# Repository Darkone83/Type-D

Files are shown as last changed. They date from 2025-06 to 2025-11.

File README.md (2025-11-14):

# Type D: Original Xbox TFT Display Project

<div align=center>
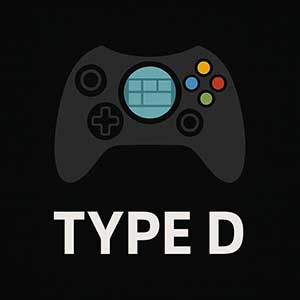
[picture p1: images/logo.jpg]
  

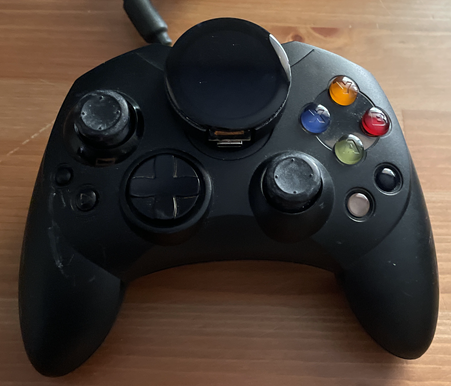
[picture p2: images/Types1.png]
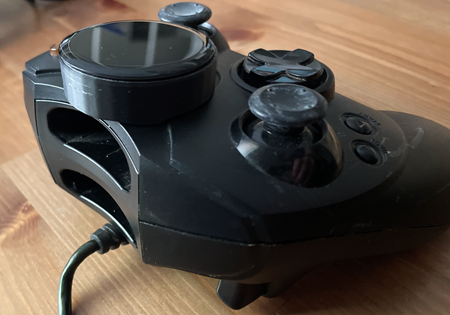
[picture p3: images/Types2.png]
  

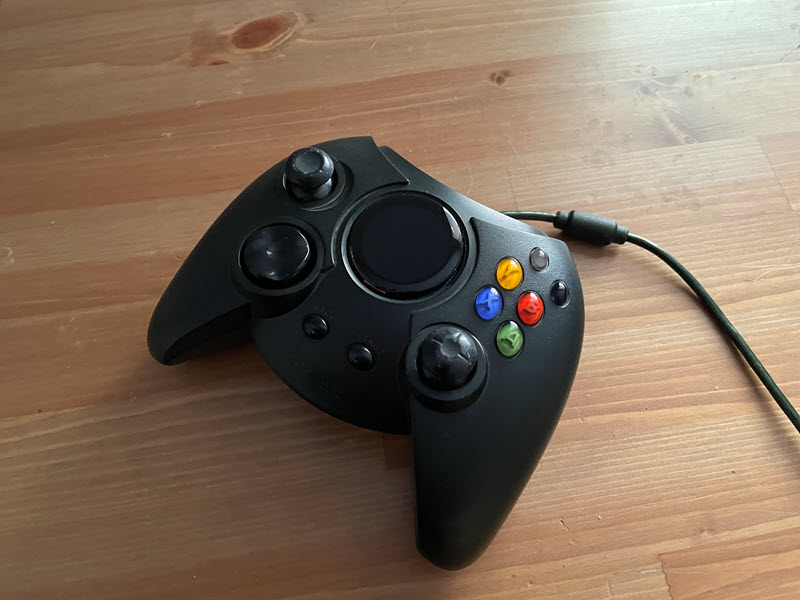
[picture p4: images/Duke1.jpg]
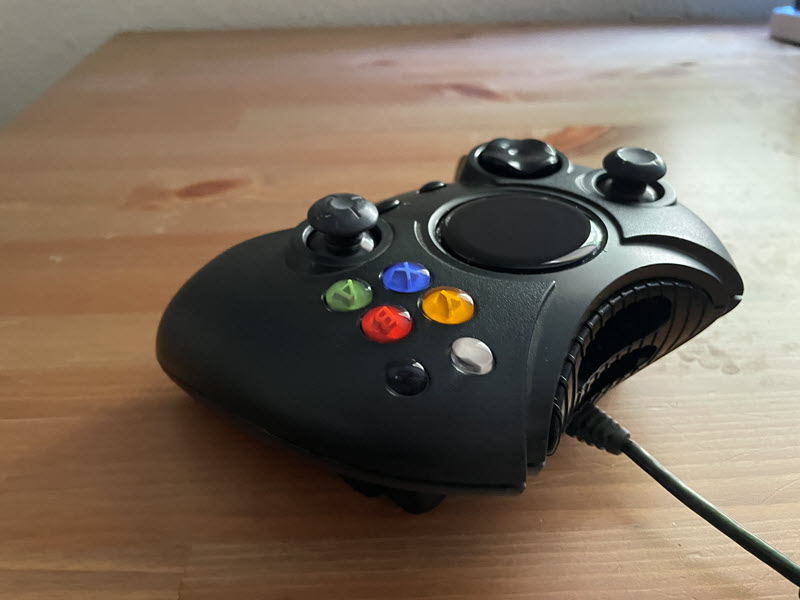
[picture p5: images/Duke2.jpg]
    
</div>



**Type D** is a two-part open-source system for the original Xbox, bringing a modern, customizable, and fully themed display experience to your console. It replaces the stock jewel with a 240x240 TFT touch display, controlled by an ESP32-S3, and optionally pairs with the Type D Expansion module for live Xbox status telemetry.

---

## Features

### Type D Display Firmware

- Animated boot screen from `/boot/boot.jpg` or `/boot/boot.gif`  
- Image & GIF slideshow: Will select a random image on boot and process through them
- Touchscreen Xbox-style menu:    
  - Adjust brightness
  - View current WiFi information    
  - Initiate WiFi setup or reset WiFi credentials  
- Web interface: Upload and manage gallery images over WiFi  

## Required Hardware

- **Type D Display**: ESP32 module (recommended: ESP32 + 240x240 TFT round GC9A01 display + CST816S touch panel + SD card support)

**AliExpress** <a href="https://www.aliexpress.us/item/3256805458117676.html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">ESP32-TFT 1.28 inch display</a>

**Amazon** <a href="https://www.amazon.com/dp/B0DLNMG2KP?ref=ppx_yo2ov_dt_b_fed_asin_title">1.28 inch ESP32-Development board</a>

- **Mounting Screws** 4 2x10 mm pan head screws (only required for the Type S installation)

- **Type S** Drill guide, and bezel plate (In the STL folder)

- **Duke** Cutting template, and spacer (In the STL folder)

## Purchasing

- **Full kit** Darkone Customs (Coming soon!)

- **Display with bezels** <a href="https://www.darkonecustoms.com/store/p/type-d-screen-kit">Darkone Customs (Type S)</a>

- **Expansion Module** <a href="https://www.darkonecustoms.com/store/p/type-d-telemetry-expansion">Darkone Customs</a>

- **Memcard PCB** <a href="https://www.darkonecustoms.com/store/p/type-d-memcard-pcb">Darkone Customs</a>. Installation instructions can be found <a href="https://github.com/Darkone83/Type-D/tree/main/pcb">here</a>.

---

## Required Libraries

_Install these via Arduino Library Manager or from their GitHub releases:_

- [`LovyanGFX`](https://github.com/lovyan03/LovyanGFX)
- [`CST816S`](https://github.com/fbiego/CST816S) by fbiego
- [`AnimatedGIF`](https://github.com/bitbank2/AnimatedGIF)
- [`ESPAsyncWebserver`](https://github.com/me-no-dev/ESPAsyncWebServer)
- [`ESPAsyncTCP`](https://github.com/me-no-dev/ESPAsyncTCP)

---

## Build Instructions

### Type D Display 

#### Web Flasher: 

#### Build Instructions
1. **Install Arduino IDE** (recommended 2.x or later).
2. **Install the ESP32 board package**
3. **Install all required libraries** (see above).
4. **Setup board and options** Board** ESP32 Dev module, Flash size: 16MB, Partition Scheme: 16MB Flash (2MB APP/12.5MB FATFS), PSRAM: Enabled
5. **Open the `Type_D.ino` project** and verify it compiles.
6. **Flash the firmware** to your module using USB.
7. **Connect to WiFi** Connect the device via wifi and select your network with the custom portal.
8. **Upload files** Log in to the File Manager via the web interface Http://"device-ip":8080 and upload your media. 
9. **Upload Resource files** Resource files can be uploaded via the resource manager Http://"device-ip":/8080/resources.

   **Notes:**
   - If no gallery images are present, a “No images found” screen will be shown.
   - File types supported are determined by firmware: common formats are `.jpg`,`.gif` (for UI assets).

## GIF Conversion

Use the script in the scripts folder to properly format your GIFS

Usage: gif_convert.py mygif.gif cool.gif

## Hardware installation

### Display Preparation

1 **Solder jumper** You will need to solder the jumper pad to the leg directly next to it to bypass the power button. See the Image below for reference.
<div align=center>

  ESP32
  
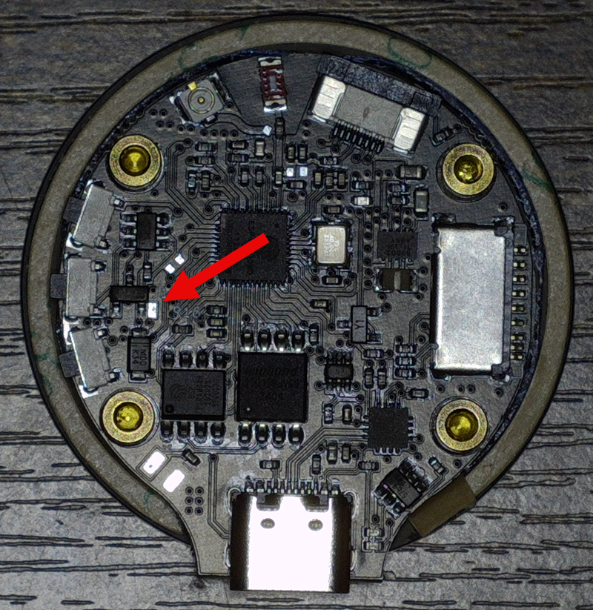
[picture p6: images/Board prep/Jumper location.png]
  

  ESP32-S3
  
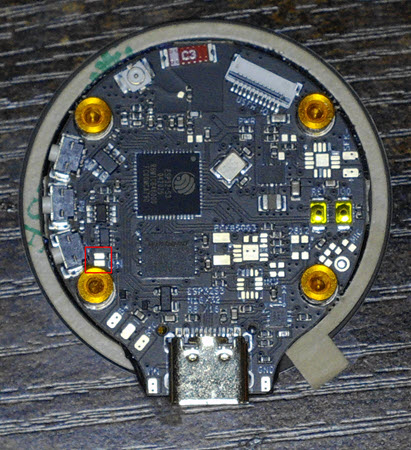
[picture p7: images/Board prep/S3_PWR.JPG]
  
</div>

2 **Locate power**: Reference the image below for positive and negative terminals. Pre-tin the negative pad with a bit of flux and decent solder.
<div align=center>

  ESP32
  
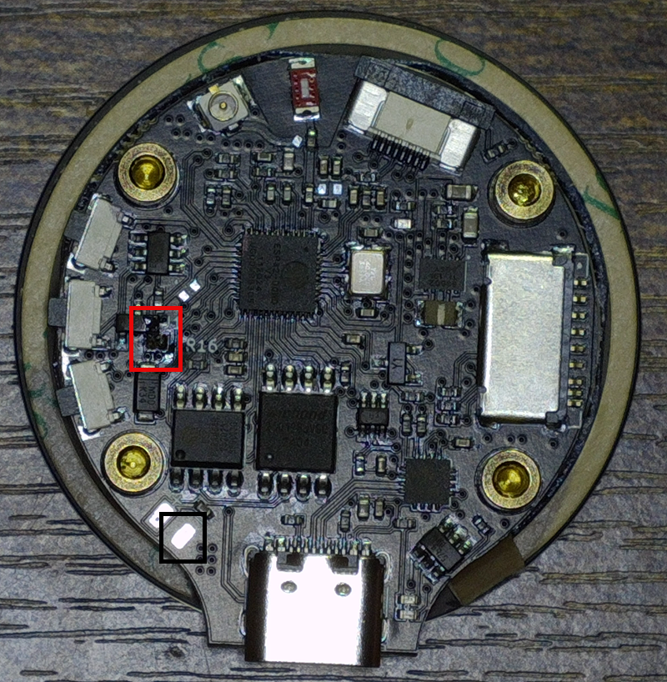
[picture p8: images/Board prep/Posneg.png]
  

  ESP32-S3
  
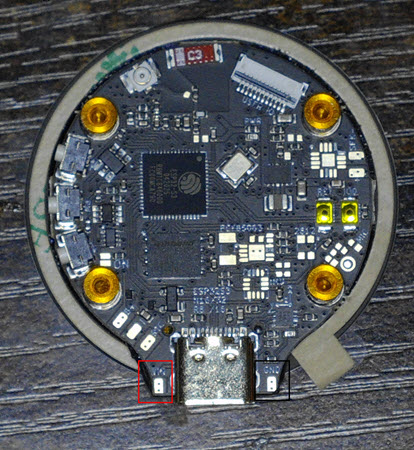
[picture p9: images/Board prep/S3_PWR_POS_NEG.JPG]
  
</div>

3 ** Install power wires** Trim your leads as short as possible and solder your positive and negative conductors. Silicone sheathed wire is recommended for routing and flexibility.
<div align=center>
  
  Zoomed in ESP32:

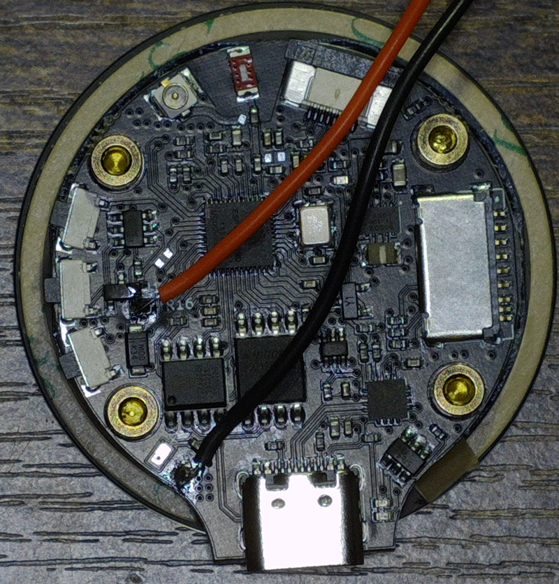
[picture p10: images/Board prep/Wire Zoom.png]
  

  Zoomed out ESP32:

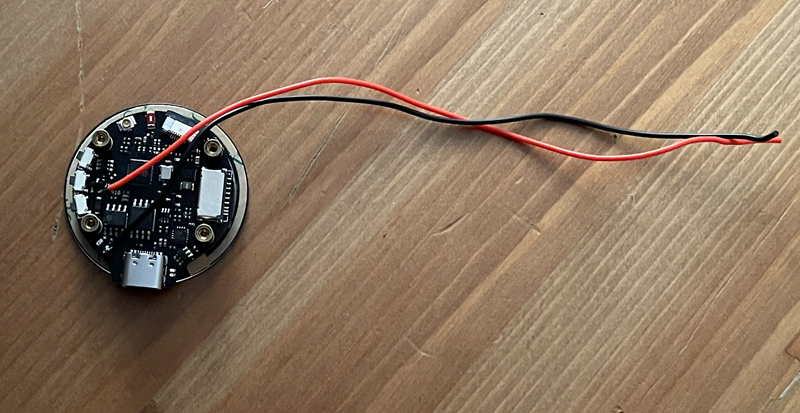
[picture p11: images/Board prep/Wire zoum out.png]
  

  Zoomed in ESP32-S3:

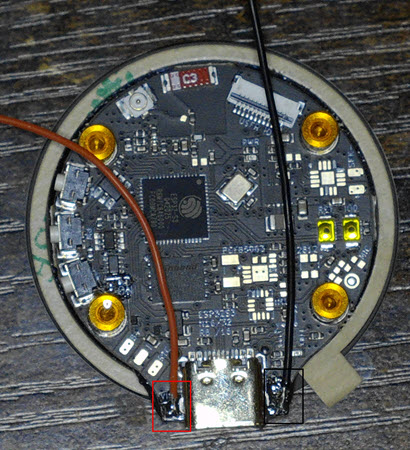
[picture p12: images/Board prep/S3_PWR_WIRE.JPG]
  

### Type S:

**Notice** Beyond this point, you will be physically modifying your controller. This is not reversible, as you will have to drill holes in your shell. It's strongly advised that you use a shell that you're potentially alright with modifying.

**Required** You will need the <a href="https://github.com/Darkone83/Type-D/blob/main/stl/Type%20S%20Drill%20guide.stl">Type S drill guide</a> and the <a href="https://github.com/Darkone83/Type-D/blob/main/stl/Type%20S%20Bezel.stl">Type S Bezel</a>. You can asso use the optional <a href="https://github.com/Darkone83/Type-D/blob/main/stl/Washer.stl">washer</a> if needed.

<div align=center>
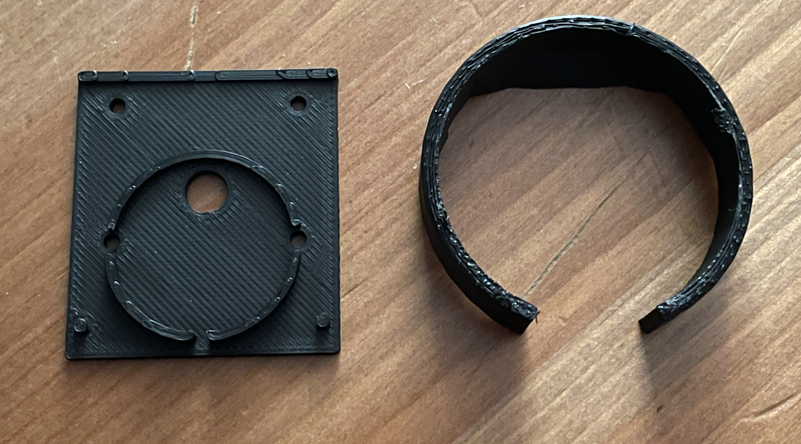
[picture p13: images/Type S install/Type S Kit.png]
  
</div>

1 **Install Bezel** Peel the release paper from the screen and adhere it to the bezel
<div align=center>
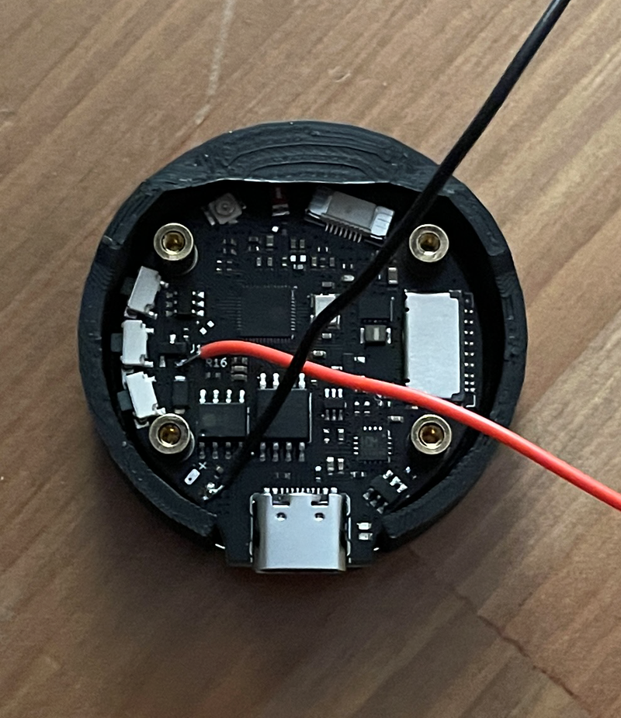
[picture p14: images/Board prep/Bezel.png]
  
</div>

2 **Remove jewel** Remove your jewel with a spudger or soft tool

<div align=center>
  Before:

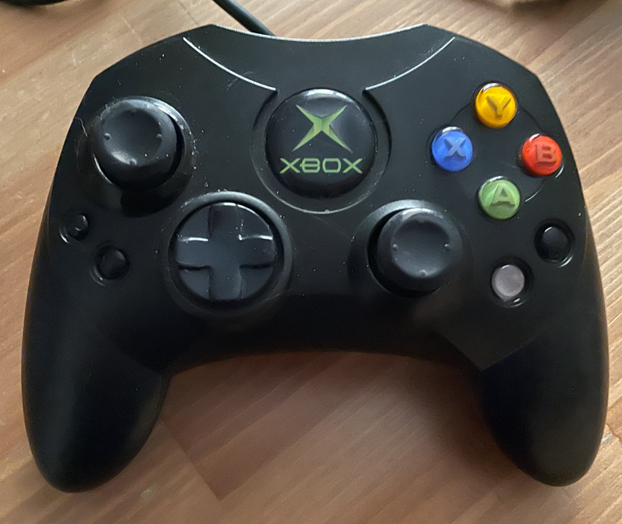
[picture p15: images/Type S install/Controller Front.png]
  

  After:

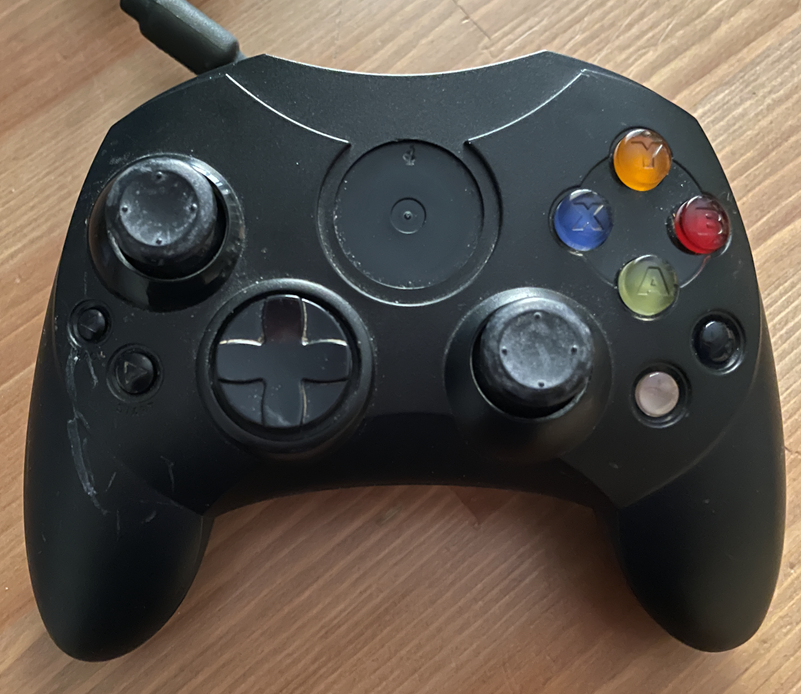
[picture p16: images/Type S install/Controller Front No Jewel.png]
  
</div>

3 **Unscrew controller** Remove all screws shown in the image below
<div align=center>
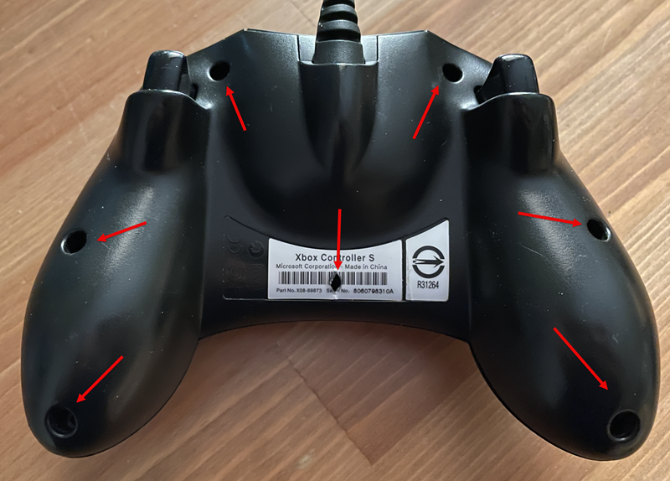
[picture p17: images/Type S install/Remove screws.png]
  
</div>

4 **Prep power points** Remove the PCB and prep your positive and negative points 
<div align=center>
  PCB Back:

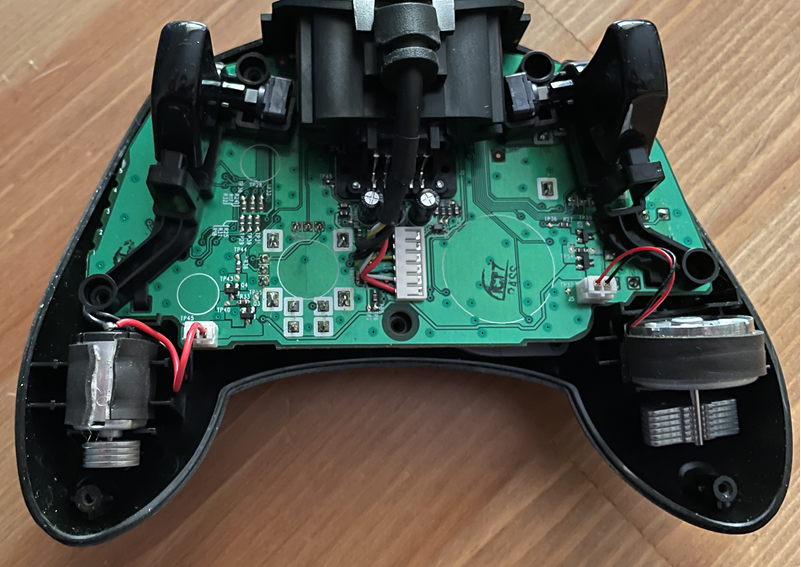
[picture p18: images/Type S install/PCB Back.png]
  

  Positive and Negative Points:

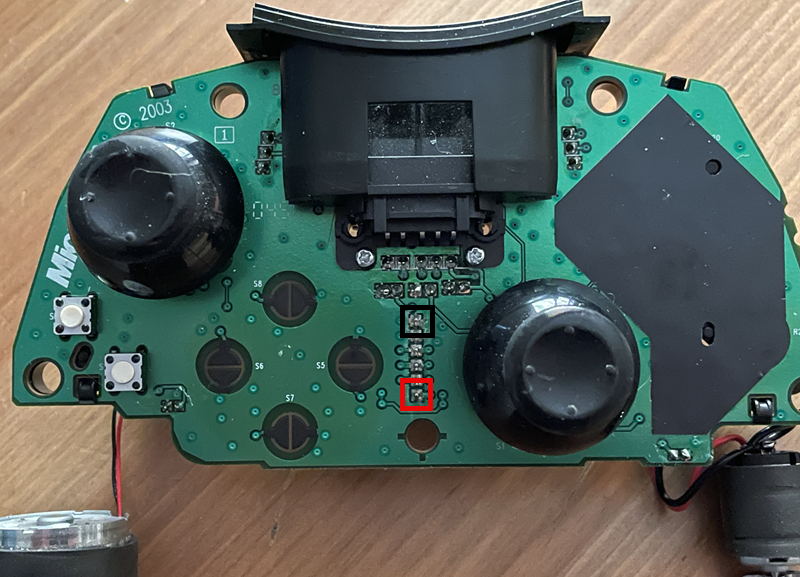
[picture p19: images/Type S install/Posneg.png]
  
</div>

5 **Place Drill Guide** Take your time with this step and ensure you have good alignment
<div align=center>
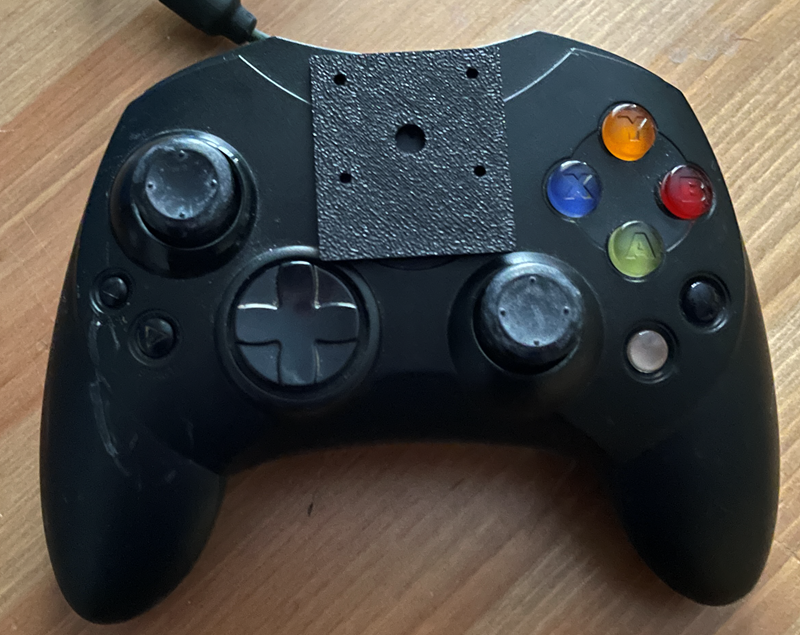
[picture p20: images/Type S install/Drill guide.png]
  
</div>

6 ** Drill holes** The point of no return, make sure you are 100% this is what you want
<div align=center>
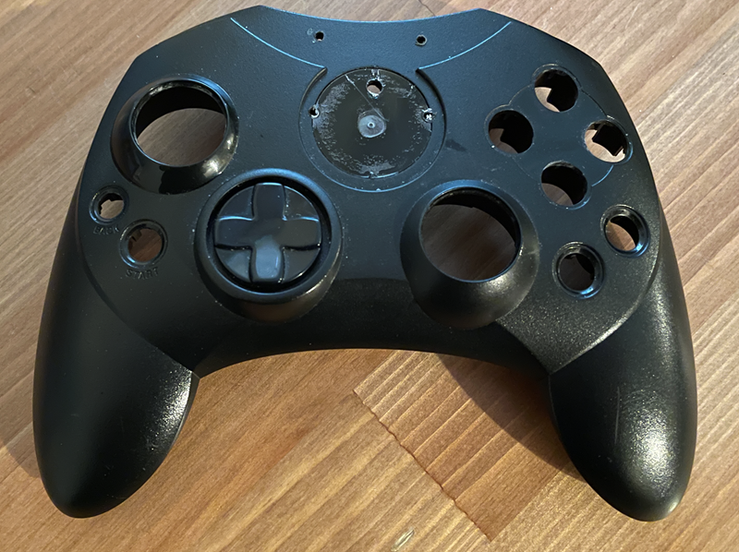
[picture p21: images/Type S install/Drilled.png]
  
</div>

7 **Secure Display** Install screws and secure the display to the controller
<div align=center>
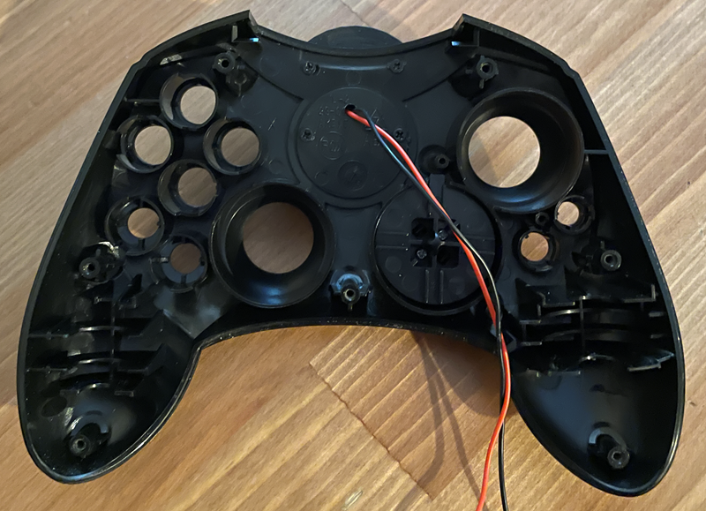
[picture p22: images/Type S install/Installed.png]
  
</div>

8 **Trim and solder conductors** Trim and solder your conductors to the correct positive and negative points. It's highly advised to test at this point
<div align=center>
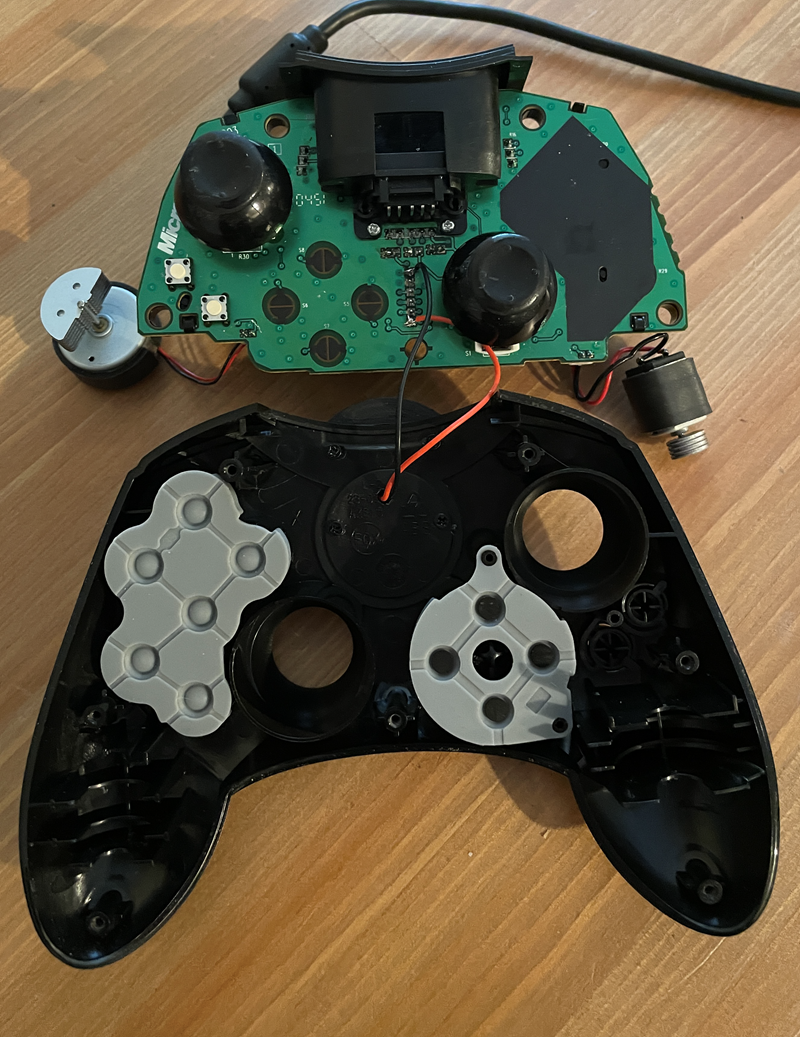
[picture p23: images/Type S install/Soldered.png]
  
</div>

9 **Reassembly** Reassemble your controller and enjoy!

### Duke:

1 **Additional Board Prep** Remove the 4 screw standoffs. This can be done with a soldering iron, but will be required if you don't want to trim the top memory card port.

<div align=center>
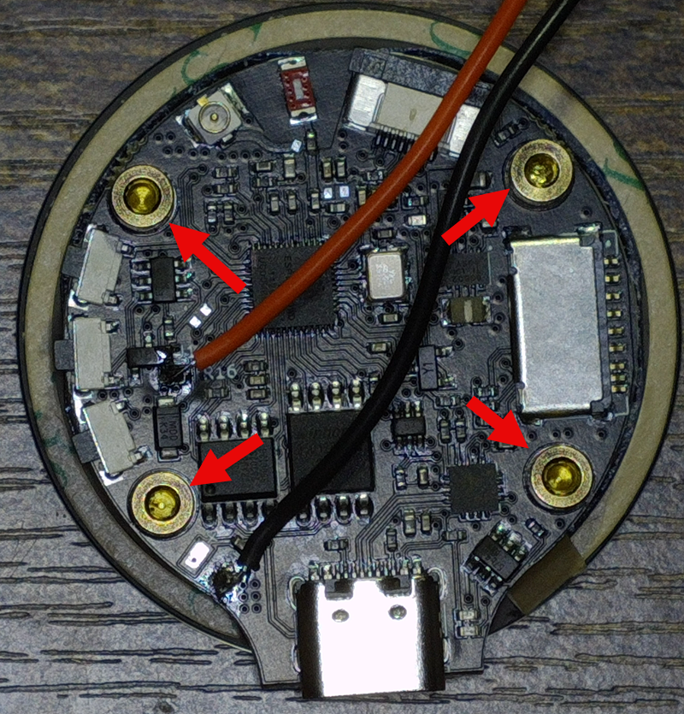
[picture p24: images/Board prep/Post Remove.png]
  
</div>
2 **Disassemble the shell** Disassemble your Duke controller. Please note that the plastic is very brittle on these controllers; go slow and take your time.

<div align=center>
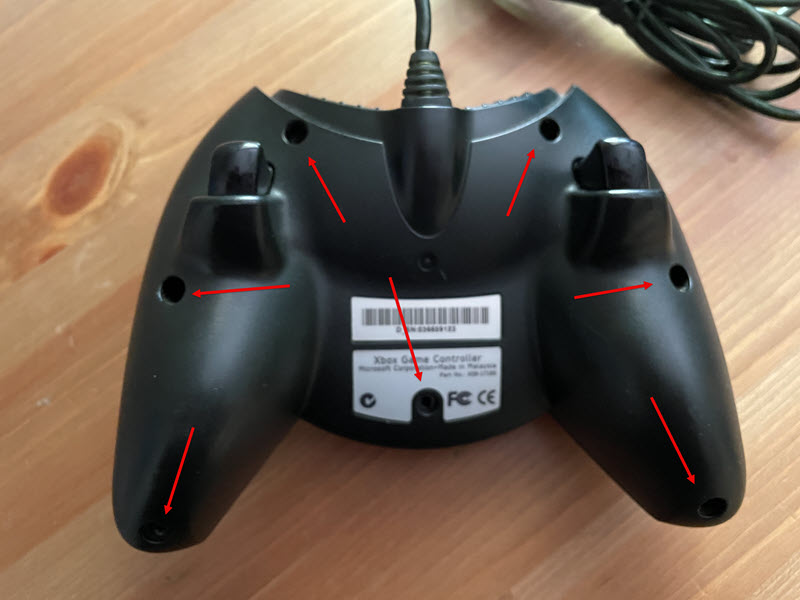
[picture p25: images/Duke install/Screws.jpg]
  
</div>

3 **Front faceplate prep** Remove your front faceplate on the back; you will see a tab that sticks up, which will need to be trimmed, revealing the snap to the top jewel of the controller. Use a screwdriver to gently push the tab and remove the jewel from your controller.

<div align=center>
Front:

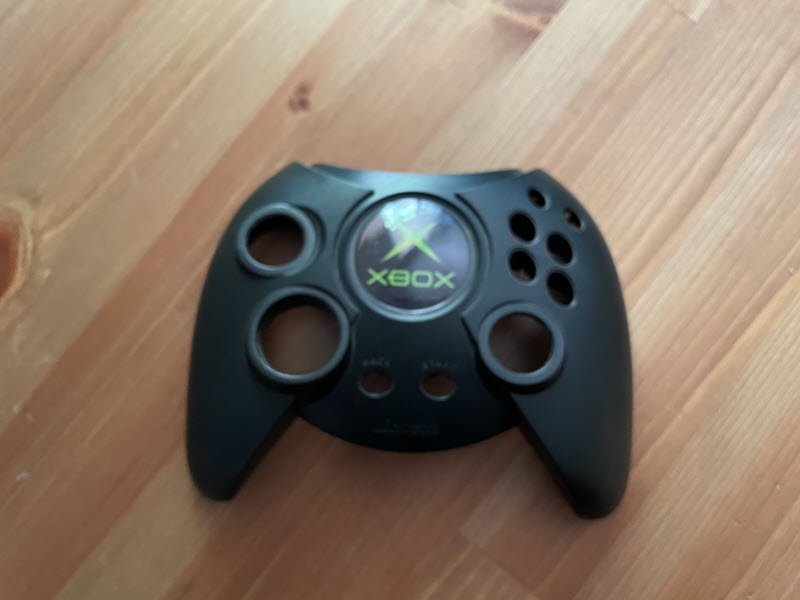
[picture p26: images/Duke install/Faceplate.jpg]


Area to cut first:

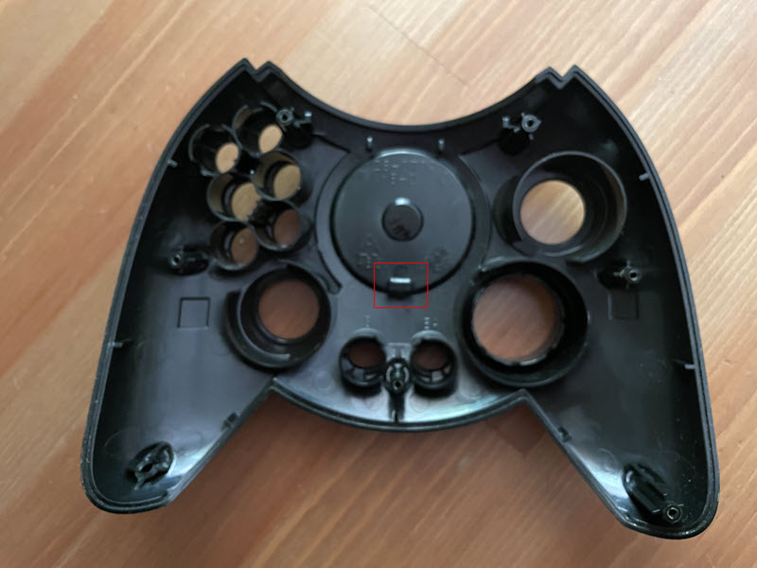
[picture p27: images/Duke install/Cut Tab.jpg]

</div>

4 **Cut the opening** Place the <a href="https://github.com/Darkone83/Type-D/blob/main/stl/Duke%20Guide.stl">cutting guide</a> where your jewel used to reside and mark your area to cut. For this install, I opted to go with a hot knife as the plastic is already extremely brittle. Go slow and take your time. Test for the display fitment along the way and trim as needed.

<div align=center>
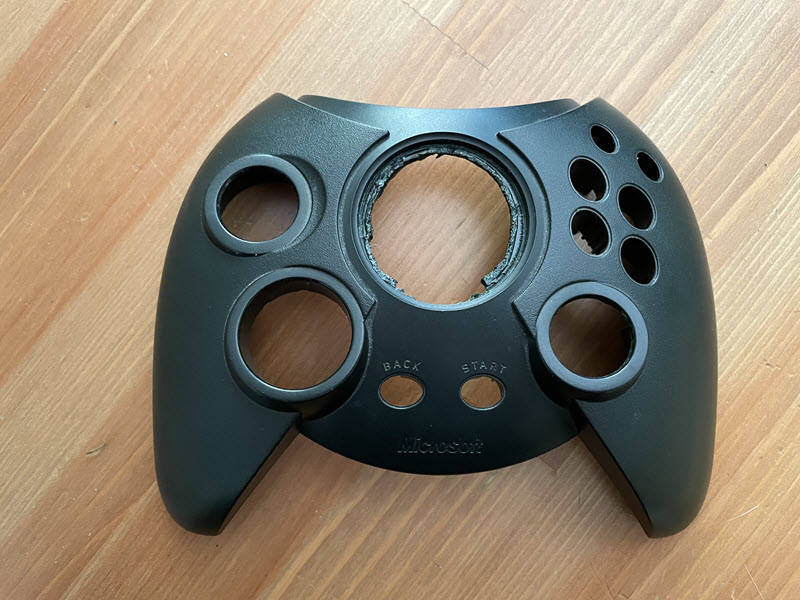
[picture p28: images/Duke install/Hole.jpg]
  
</div>

5 **Install spacer** Install your spacer with some super glue. The <a href="http://github.com/Darkone83/Type-D/blob/main/stl/Duke%20Spacer.stl">spacer</a> can be downloaded in the STL folder. Trim the shell as needed.

<div align=center>
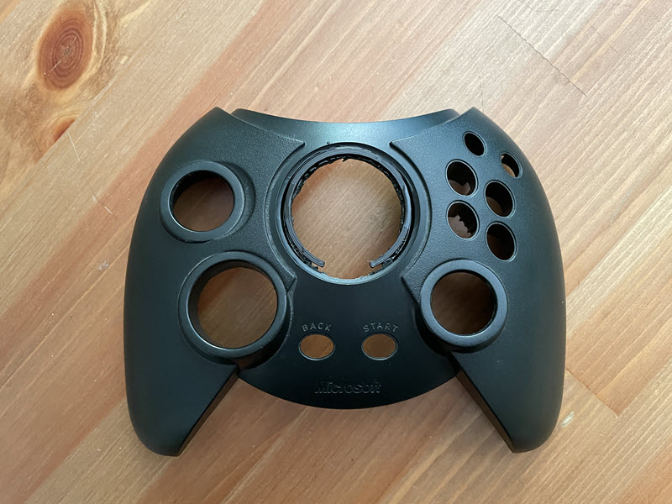
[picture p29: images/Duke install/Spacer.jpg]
  
</div>

6 **Install display** Fit your display by removing the release paper and adhering it in place. Take your time with alignment.

<div align=center>
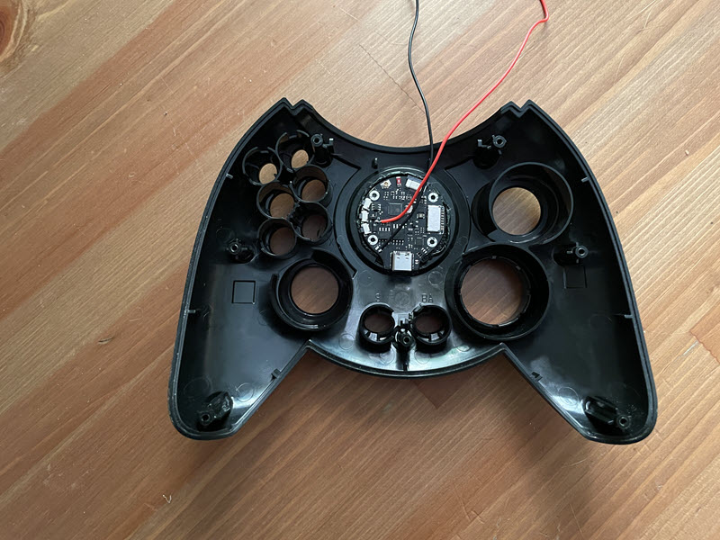
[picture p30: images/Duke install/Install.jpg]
  
</div>

7 **Locate power** Locate Positive and Negative on your controller. Reference the image below.

<div align=center>
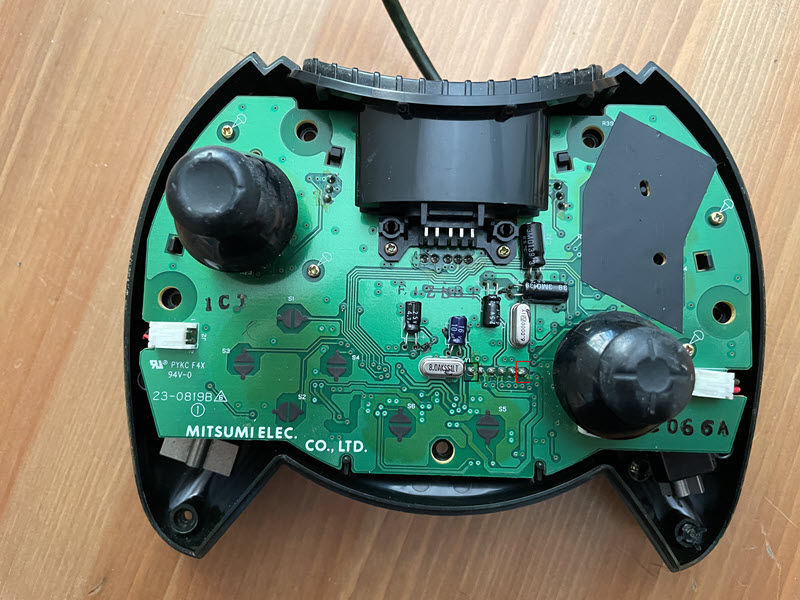
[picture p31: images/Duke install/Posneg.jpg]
  
</div>

8 ** Install power wires** Trim and install the conductors as seen below.

<div align=center>
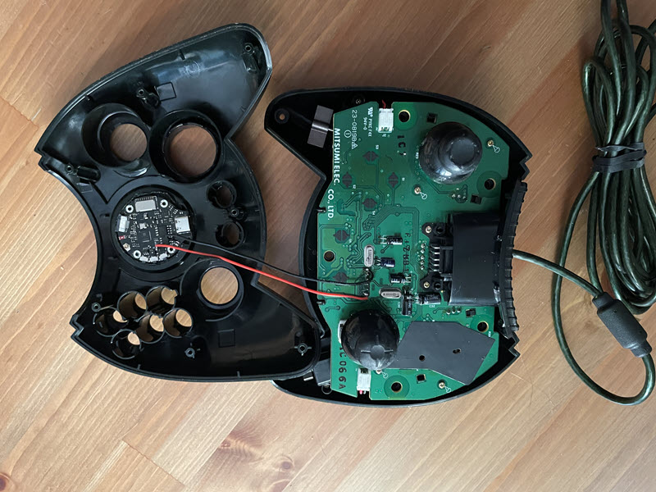
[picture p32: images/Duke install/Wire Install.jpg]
  
</div>

9 **Reassemble and enjoy** Reassemble your controller and enjoy!

## WiFi Connection:

Set up your WiFi by joining the Type D setup wifi network that Type D broadcasts. Join your preferred network and access the file manager to upload your content with the built-in file manager Http://"device ip":8080

## 🗺️ Navigation & Menu Tree

**Main Menu Structure:**
```
[ Main Menu ]
 ├─ Settings
 │    ├─ Brightness
 │    └─ WiFi info
 │    └─ Forget WiFi
 │    └─ Back
 ├─ About
 └─ Exit
```

### Navigation

- **Touch**
  - *Single tap*: Select menu item
  - *Swipe up/down*: Scroll through menus or items
  - *Double tap*: Enter Type D Menu
- **Settings Menu**
  - *Brightness*: Adjust display backlight (0-100%)
  - *WiFi Info*: Displays current WiFi network connection and IP address
  - *Forget WiFi*: Forgets WiFi settings and restarts the connection portal
  - *Back*: Returns to main menu
- **About**: Shows build/version info and credits
- **Exit**: Exits menu
---

## How It Works

- **Type D Display** runs as a stand-alone smart dashboard and animated photo frame, displaying images and menus when no Xbox is online.
- When a **Type D Expansion** module is active, the display instantly receives Xbox system telemetry and shows a themed overlay with the latest status—no configuration required. (Still in development)

---

## Diagnostics

You can access the diagnostic page once you have connected to wifi by visiting HTTP://"device IP":8080/diag

## Notes

- GIF support is experimental! Keep your GIF's under 1MB. Larger GIF's may work, but cause crashing of the firmware.

___

## Special Thanks

- Andr0, Team Resurgent, Cat-Pog-Real (STL Design), Xbox Scene, and the Xbox modding community

---

**Questions, feedback, or want to contribute? Open an issue or PR on GitHub!**

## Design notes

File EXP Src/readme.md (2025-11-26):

# Type D EXP

Firmware for the Waveshare ESP32-S3-Zero, featuring UDP-based status reporting.

## Required Hardware

Waveshare ESP32-S3 Zero (clones will work, but LED RGB value may need adjustment)

<a href="https://www.amazon.com/dp/B0CS6VS1DJ?ref_=ppx_hzsearch_conn_dt_b_fed_asin_title_2">Amazon</a>

## Build Instructions (Arduino IDE)

1. **Board Setup**  
   - Open Arduino IDE.  
   - Go to **Tools → Board → ESP32 Arduino → ESP32S3 Dev Module**.  
   - Select your **Port** under **Tools → Port**.

2. **Project Files**  
   - Copy all project files (including `Type_D_EXP.ino` and related `.cpp`/`.h` files) into your Arduino sketch folder.

3. **Install Libraries**  
   - AsyncTCP  
   - ESPAsyncWebServer  

5. **Build and Upload**  
   - Open `Type_D_EXP.ino` in Arduino IDE.  
   - Click **Upload**.
   - **If your using a clone board** : adjust line 17 in led_stat.cpp by default ir reads `neopixelWrite(RGB_PIN, g, r, b);` change it to `neopixelWrite(RGB_PIN, r, g, b);` in order top get proper RGB colors on clone boards.

#### Web Flasher: 

## PCB

You can grab the PCB for a cleaner mounting solution in the PCB folder.

## Installation

Solder SDA from the LCP header to Pin 7, SCL from the LPC to pin 6, GND to GND, and 5v from the LPC (or any other source) to 5v on the S3

Mount to the RF shield with VHB tape or foam tape

## Connect to your wifi network

Locate and join the Type D EXP Setup network, and join your preferred wifi network. Both Type D and Type D EXP need to be on the same network to work properly.

## 📱 Get the App

Download on the App Store (https://apps.apple.com/us/app/type-d-viewer/id6755620952)

Download the **Type D Viewer** app for iOS to view live telemetry data from your XBOX.

## LED Statuses

- White: Booting
- Blinking Purple: WiFi portal active
- Green: connected to WiFi
- Red: Wifi connection failed
- Orange blink: UPD Packet send *now working* will show the status approx every 5 seconds

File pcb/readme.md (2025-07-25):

# Memcard Installation

<div align=center>
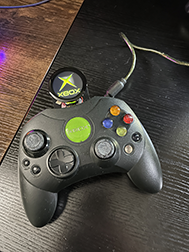
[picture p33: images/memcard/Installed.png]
  

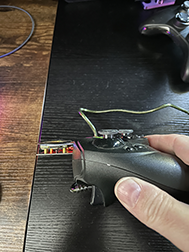
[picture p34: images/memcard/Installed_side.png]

</div>

For those that want a no-cut mod here it is the memoru card install.

<div align=center>
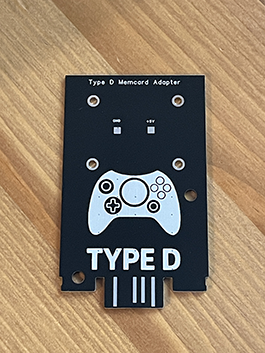
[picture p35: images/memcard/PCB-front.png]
  

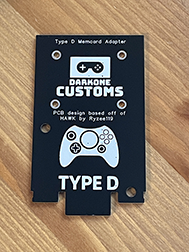
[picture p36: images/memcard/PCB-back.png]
  
</div>

---

## Require hardware

- Type D Display
- memcard PCB
- Silicone wire
- 4x 2m screws 4mm in length

## Installation

1. **Prep Type D** follow the preparation instructions for your variant. They can be found <a href="https://github.com/Darkone83/Type-D/">here</a>.

2. ** Prep the memcard PCB** Solder your wires to the memcard PCB.
<div align=center>
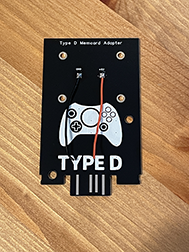
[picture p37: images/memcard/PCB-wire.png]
  
</div>

3 ** Solder to the Type D**  Solder your conductors to the Type D.
<div align=center>
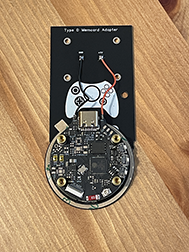
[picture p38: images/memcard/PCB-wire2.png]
  
</div>

4 **Align screw holes** Line up your screw holes and install your 4 2m x 4mm screws. Do not overtighten as you will strip out the standoffs.
<div align=center>
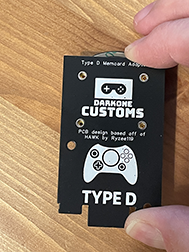
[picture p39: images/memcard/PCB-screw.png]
  

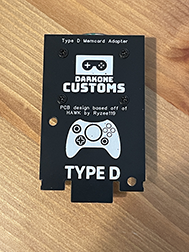
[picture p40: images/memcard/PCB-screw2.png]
  
</div>

5 **Admire your handy work** You did it enjoy your Type D memcard.
<div align=center>
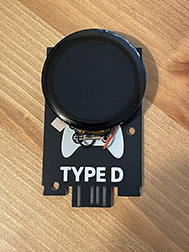
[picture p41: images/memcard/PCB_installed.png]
  
</div>

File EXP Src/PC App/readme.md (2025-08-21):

<div align=center>
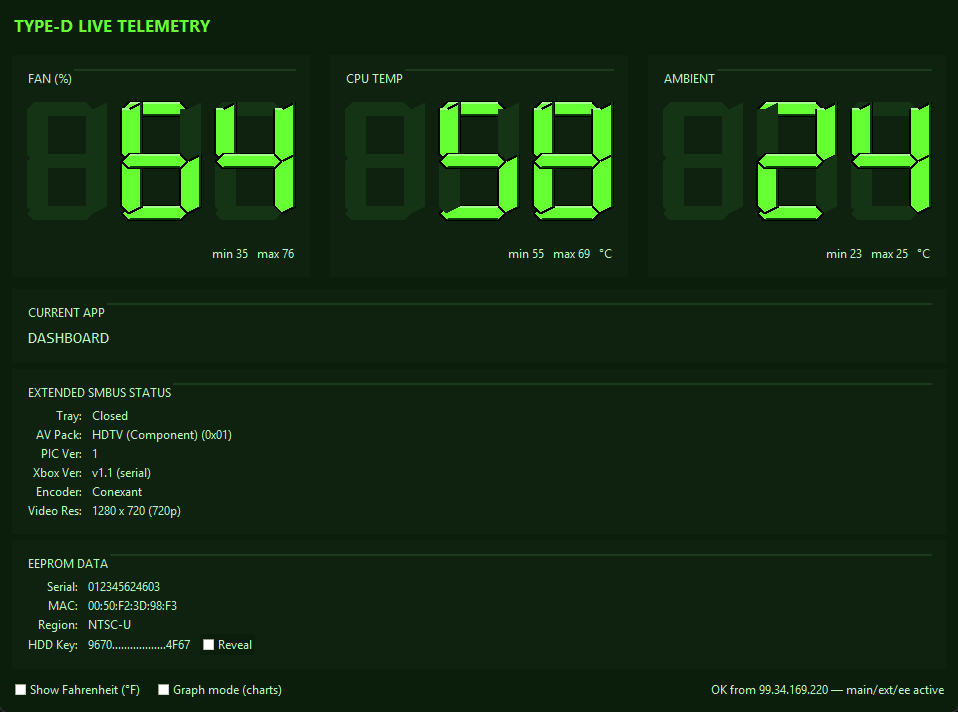
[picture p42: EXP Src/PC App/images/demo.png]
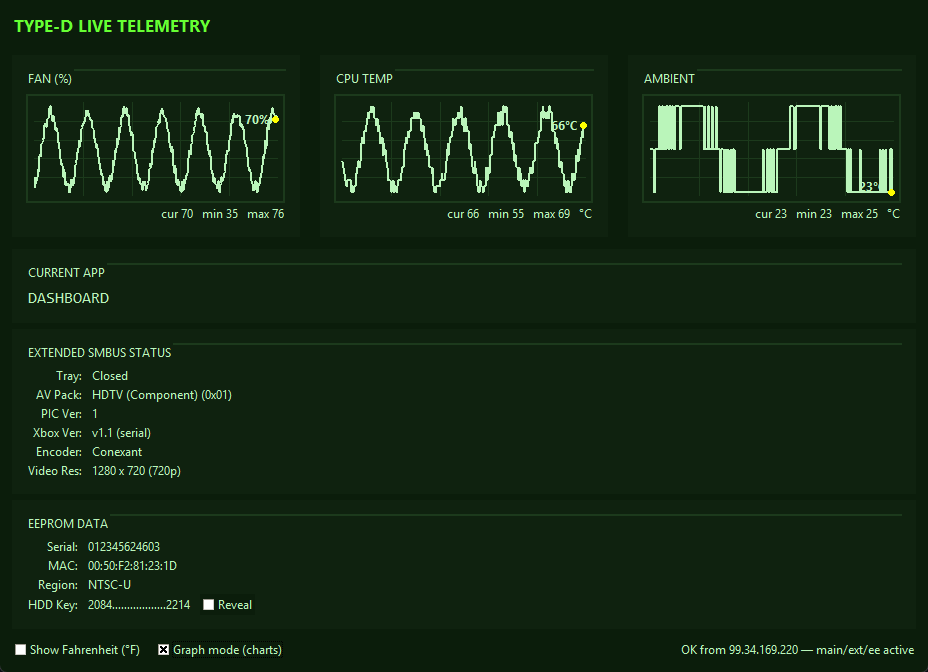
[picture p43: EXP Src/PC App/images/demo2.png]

</div>

# Usage

The app needs to be running on a computer thats on the same network as the Type-D Telemetry unit. Once detected the stast will auto fill.

The original python script will be in the script folder in this directory

## Features

* Live telemetry dashboard: Fan %, CPU temp, Ambient temp, and Current App in an OG Xbox–styled UI.

* Graph mode: grid background, yellow “current” dot, floating value label, min/max/current readouts, and °C/°F toggle.

* Extended console status: Tray state, AV pack type (robust decode), PIC version, encoder (Conexant/Focus/Xcalibur), and video resolution with 480i/p, 576i/p, 720p, 1080i inference.

* Xbox version detection: prefers EEPROM serial mapping; falls back to encoder family; finally uses SMC code if available.

* EEPROM panel: shows Serial, MAC, Region, and HDD key* (masked with “Reveal” toggle); resilient parsing from raw 256-byte dump with fallback layouts.

* Time-windowed history: charts keep a fixed wall-time window (configurable; default ~10 minutes), independent of packet rate.

* Compatibility: accepts multiple EEPROM message formats and any field order for encoder/width/height; tolerates missing or partial data.

* Theming & polish: consistent Xbox-green palette, beveled 7-segment displays, compact single-window layout.
  
*HDD feature is still being worked on and may not produce an actual key

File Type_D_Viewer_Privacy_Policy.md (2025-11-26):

# Type D Viewer – Privacy Policy

_Last updated: 2025-11-21_

## Overview
Type D Viewer respects your privacy. This application does **not** collect, store, transmit, or share any personal information. All data displayed within the app remains on your device at all times.

## Information We Do Not Collect
### No Personal Data
Type D Viewer does not collect or request:
- Your name
- Email address
- Phone number
- Account information
- Contact lists
- Photos, camera data, or files

### No Tracking
We do not:
- Track you across apps or websites
- Use analytics services
- Use advertising identifiers
- Collect usage statistics
- Implement third-party tracking SDKs

### No Location Access
Type D Viewer does not access your GPS or location services.

## Local Network Access
Type D Viewer uses **Local Network** permissions strictly for the app’s core functionality:  
**discovering and reading telemetry from compatible devices on your local network.**

The app does **not**:
- Transmit this data outside your device  
- Store it remotely  
- Share it with third parties  

All telemetry data is processed **entirely on your device** and is discarded when the app is closed.

## Data Storage
Type D Viewer:
- Does **not** upload data  
- Does **not** store any logs  
- Does **not** save data outside the app’s runtime  
- Does **not** use cloud storage or external servers  

Sensitive values displayed within the app (such as identification keys) are shown **locally only** and may be masked by default for user safety.

## Third-Party Access
No data is shared with:
- External servers  
- Advertisers  
- Analytics providers  
- Third-party partners  

We do not sell or disclose any information because **we do not collect any information** in the first place.

## Children’s Privacy
Type D Viewer does not collect personal information from anyone, including children under 13 years of age. The app is safe for all users.

## Changes to This Policy
If the privacy policy changes in the future, the updated version will be included with an updated release of the app. Type D Viewer will never weaken your privacy protections without informing you.

## Contact
If you have questions about this policy or privacy within the app, you may contact us at:

**support@darkonecustoms.com**

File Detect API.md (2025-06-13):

# Type D Device Detection Module

This module enables each Type D device to automatically assign itself a unique device ID (1–4) on a local network. It uses UDP broadcast for zero-configuration discovery, dynamic ID assignment, and ongoing conflict detection—no manual setup required.

---

## How Detection Works

- **On startup**, the device broadcasts a discovery message over UDP to all peers.
- Each active device responds with its current ID.
- The new device collects all responses, notes which IDs are in use, and picks the **lowest unused ID** in the range 1–4.
- Once assigned, the device broadcasts its ID to peers at regular intervals for ongoing presence and collision detection.
- If a conflict is detected (i.e., another device responds with the same ID from a different IP), the device automatically attempts to reassign a unique ID.

---

## API (C++)

All functions are in the `Detect` namespace:

```cpp
namespace Detect {
    void begin();              // Call once in setup() after WiFi is connected
    void loop();               // Call regularly in your main loop()
    uint8_t getId();           // Returns the current assigned device ID (1–4)
    void assignId();           // Manually trigger a new ID scan/assignment
    void broadcastId();        // Immediately announce your current ID
    void checkIdConflict();    // Scan immediately for ID conflicts
}
```

---

## Usage Example

```cpp
#include "detect.h"

void setup() {
    // ... (WiFi/network setup code) ...
    Detect::begin(); // Start device detection
}

void loop() {
    Detect::loop();  // Regular detection processing
    // ... (other application code) ...
}

// To get your device's current unique ID at any time:
uint8_t myId = Detect::getId();
```

---

## Main Functions

| Function | Description |
|---|---|
| `Detect::begin()` | Initialize detection system; call after WiFi setup |
| `Detect::loop()` | Periodically handles broadcast, assignment, conflicts |
| `Detect::getId()` | Returns current device ID (1–4) |
| `Detect::assignId()` | Triggers immediate ID re-assignment |
| `Detect::broadcastId()` | Broadcasts current ID now (advanced use) |
| `Detect::checkIdConflict()` | Checks for conflicting IDs immediately |

---

## Detection Protocol

- **Discovery:**  
  Device sends a UDP broadcast to all peers at startup.
- **Response:**  
  Devices reply with their active ID (`TYPE_D_ID:<id>`).
- **Assignment:**  
  Each device picks the lowest available ID (1–4) not in use.
- **Broadcast:**  
  Devices send their ID at regular intervals for monitoring and quick detection of new units.
- **Conflict Resolution:**  
  If a device hears its own ID used by another IP, it waits a random short time and re-triggers assignment to avoid persistent conflicts.

---

## Integration Tips

- **Always** call `Detect::begin()` in your `setup()` after WiFi is established.
- **Call `Detect::loop()`** as part of your main Arduino `loop()` to maintain detection and status.
- Use `Detect::getId()` whenever you need your assigned unique device ID in your application logic.

---

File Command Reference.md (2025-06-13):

# Type D HTTP/Serial Command API

Control this device by HTTP or Serial using the following hex-based codes.

## HTTP Usage

- Endpoint: **`GET /cmd?c=XX[&param=VAL]`** (on port 8080)
    - Example: `/cmd?c=01` (next image)
    - Example: `/cmd?c=20&val=50` (set brightness to 50)

## Serial Usage

- Send `c=XX[&param=VAL]` by serial (with newline/CR).
    - Example: `c=03` (random image)
    - Example: `c=20&val=80` (set brightness 80)

## Command Table

| Hex | Command | Description | Params |
|-----|---|---|---|
| 01  | NEXT_IMAGE | Show next image | |
| 02  | PREV_IMAGE | Show previous image | |
| 03  | RANDOM_IMAGE | Show random image | |
| 04  | DISPLAY_MODE | Set mode: jpg=0, gif=1, random=2 | mode=0/1/2 or mode=jpg/gif |
| 05  | DISPLAY_IMAGE | Show image (filename) | file=FILENAME |
| 06  | DISPLAY_CLEAR | Clear the display | |
| 20  | BRIGHTNESS_SET | Set display brightness | val=5-100 |
| 30  | WIFI_RESTART | Restart WiFi portal (captive portal) | |
| 31  | WIFI_FORGET | Forget WiFi network and settings | |
| 40  | REBOOT | Reboot the device | |
| 60  | DISPLAY_ON | Turn display ON (LovyanGFX) | |
| 61  | DISPLAY_OFF | Turn display OFF (LovyanGFX) | |

---

## Example Requests

- **HTTP:**  
  `GET http://<DEVICE_IP>:8080/cmd?c=20&val=70`

- **Serial:**  
  Type `c=05&file=/gif/test.gif` and press Enter.

---

## Notes

- All valid HTTP requests get `{"ok":1}` as JSON reply.
- Unknown or invalid commands log an error on Serial.
- You can extend the command set easily by adding new cases.

---

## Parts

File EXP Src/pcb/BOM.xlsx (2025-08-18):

No. | Quantity | Comment | Designator | Footprint | Value | Manufacturer Part | Manufacturer | Supplier Part | Supplier
1 | 1 | ESP32-S3-Zero | U2 | COMM-SMD_18P-P2.54-L23.5-W18.0-TL |  | ESP32-S3-Zero |  | C9900152785 | LCSC
2 | 1 | ZX-SH1.0-5PWT | XBSMB | CONN-SMD_5P-P1.00_MEGASTAR_ZX-SH1.0-5PWT |  | ZX-SH1.0-5PWT | Megastar(兆星) | C7430447 | LCSC

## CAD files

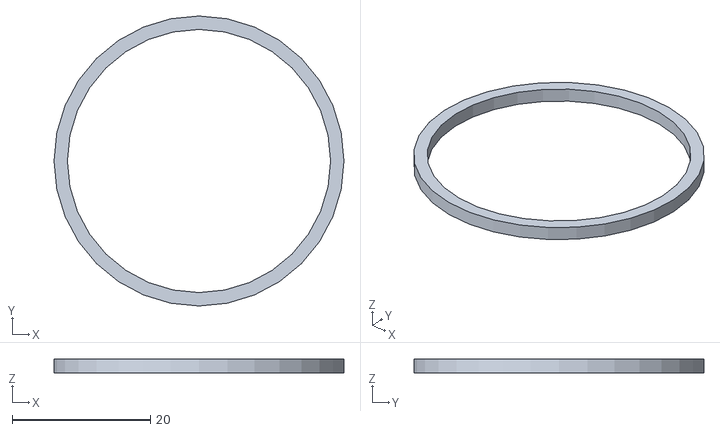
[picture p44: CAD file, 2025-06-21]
stl/Duke Guide.stl
42.0 x 42.0 x 2.00

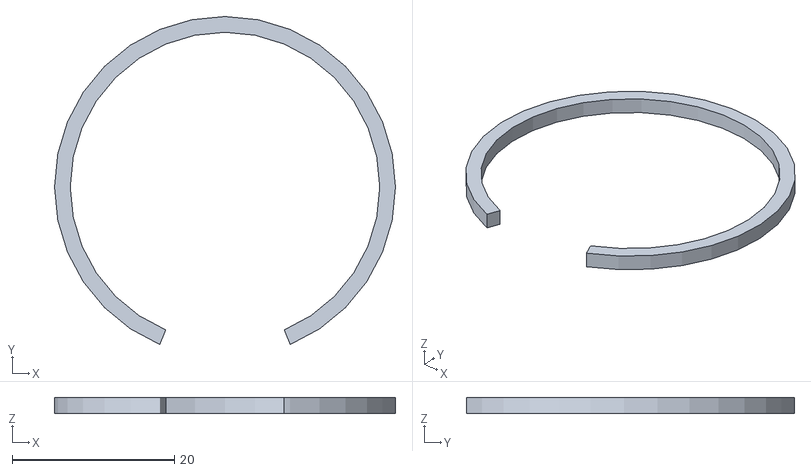
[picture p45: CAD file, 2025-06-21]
stl/Duke Spacer.stl
42.0 x 40.4 x 2.00

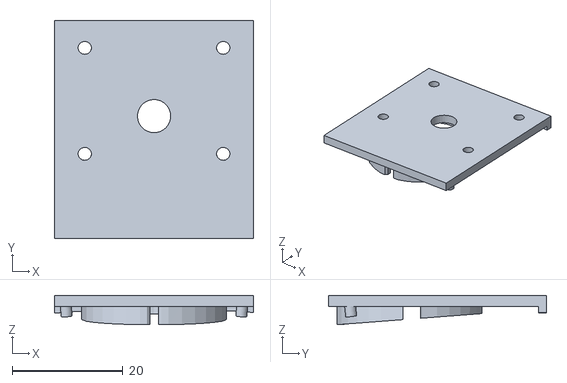
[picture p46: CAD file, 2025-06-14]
stl/Type S Drill guide.stl
36.0 x 39.5 x 5.32

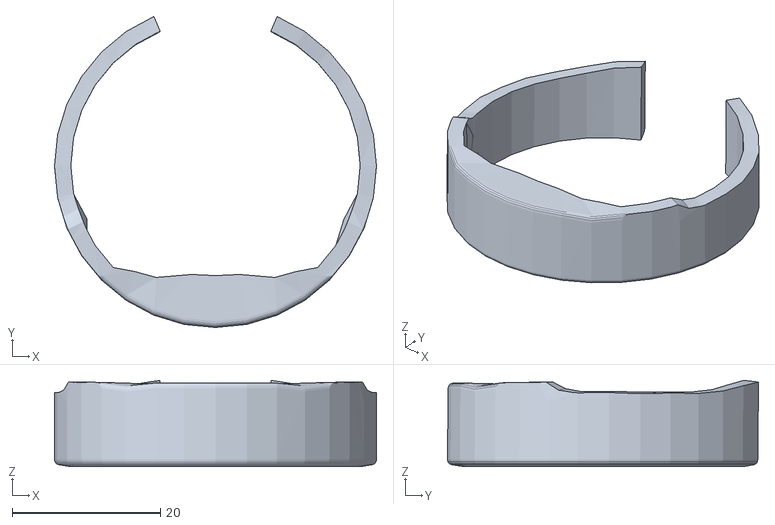
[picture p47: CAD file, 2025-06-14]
stl/Type S Bezel.stl
43.4 x 41.9 x 11.6

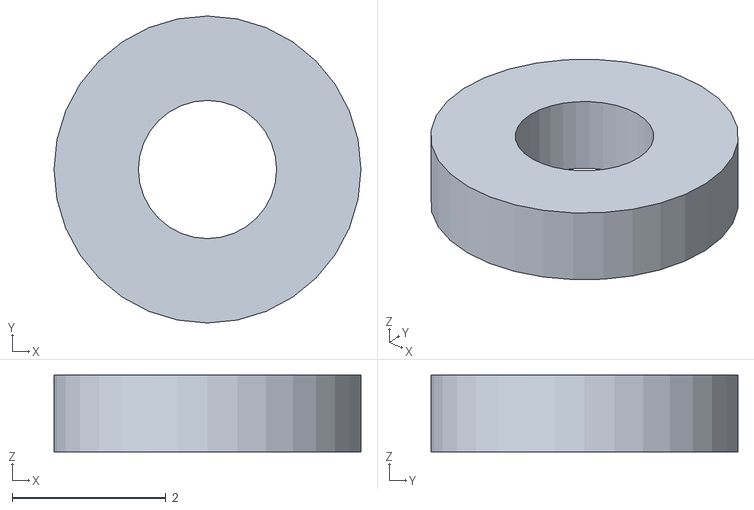
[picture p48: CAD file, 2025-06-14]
stl/Washer.stl
4.00 x 4.00 x 1.00

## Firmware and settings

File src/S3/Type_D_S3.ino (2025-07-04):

/////////////////////////
//    Type D Firmware  //
//  Code by: Darkone83 //
// Concept by: Andr0   //
// Special Thanks to:  //
//   Team Resurgent    //
//     XBOX Scene      //
//  And the modding    //
//     community       //
/////////////////////////

#include <Arduino.h>
#include "wifimgr.h"
#include <FFat.h>
#include "disp_cfg.h"
#include "detect.h"
#include "fileman.h"
#include "imagedisplay.h"
#include "boot.h"
#include <ESPAsyncWebServer.h>
#include "xbox_status.h"
#include "ui.h"
#include "ui_set.h"
#include "ui_bright.h"
#include "ui_about.h"
#include <Preferences.h>
#include "cmd.h"
#include "diag.h"
#include "udp_detect.h"

#define WIFI_TIMEOUT 120
#define BRIGHTNESS_PREF_KEY "brightness"
#define BRIGHTNESS_PREF_NS "type_d"

LGFX tft;
AsyncWebServer server80(80);
AsyncWebServer server8080(8080);


bool nowConnected = WiFiMgr::isConnected();
bool portalInfoShown = false;

static bool overlayPending = false;
static bool showingXboxStatus = false;
static unsigned long lastStatusDisplay = 0;

XboxStatus lastXboxStatus;

static int percent_to_hw(int percent) {
    if (percent < 5) percent = 5;
    if (percent > 100) percent = 100;
    return ((percent * 255) / 100);
}

void apply_brightness_on_boot() {
    Preferences prefs;
    prefs.begin(BRIGHTNESS_PREF_NS, true); // read-only
    int brightness = prefs.getUInt(BRIGHTNESS_PREF_KEY, 100); // default 100%
    prefs.end();
    if (brightness < 5) brightness = 5;
    if (brightness > 100) brightness = 100;
    tft.setBrightness(percent_to_hw(brightness));
}

// -- Show WiFi Portal Info ONLY if portal is active (not connected) --
void displayPortalInfo() {
    tft.fillScreen(TFT_BLACK);
    tft.setTextColor(TFT_YELLOW, TFT_BLACK);
    tft.setTextDatum(MC_DATUM); // center text

    tft.setTextSize(2);
    tft.drawString("WiFi Portal Active", tft.width()/2, tft.height()/2 - 30);
    tft.setTextColor(TFT_WHITE, TFT_BLACK);
    tft.setTextSize(2);
    tft.drawString("Type D Setup", tft.width()/2, tft.height()/2);
    tft.drawString("IP: 192.168.4.1", tft.width()/2, tft.height()/2 + 16);
    tft.setTextSize(1);
    tft.drawString("Connect below to setup.", tft.width()/2, tft.height()/2 + 32);
}

void setup() {
    Serial.begin(115200);
    delay(200);
    Serial.println("[Type D] Booting...");

    tft.init();
    tft.setRotation(0);
    apply_brightness_on_boot();
    tft.fillScreen(TFT_BLACK);

    ImageDisplay::begin(&tft);

    if (!FFat.begin()) {
        Serial.println("[Type D] FFat Mount Failed! Attempting to format...");
        if (FFat.format()) {
            Serial.println("[Type D] FFat format succeeded! Rebooting...");
            delay(1000);
            ESP.restart();
        } else {
            Serial.println("[Type D] FFat format FAILED! Halting.");
            while (1) delay(100);
        }
    } else {
        Serial.println("[Type D] FFat Mounted OK.");
    }
    server80.serveStatic("/resource/", FFat, "/resource/");
    server8080.serveStatic("/resource/", FFat, "/resource/");

    // --- BOOT ANIMATION ---
    bootShowScreen();

    // ---- SPLASH TEXT ----
    tft.fillScreen(TFT_BLACK);
    tft.setTextDatum(middle_center);
    tft.setTextColor(TFT_GREEN, TFT_BLACK);
    tft.setTextSize(3);
    tft.drawString("Type D", tft.width() / 2, tft.height() / 2 - 18);
    tft.setTextColor(TFT_WHITE, TFT_BLACK);
    tft.setTextSize(2);
    tft.drawString(VERSION_TEXT, tft.width() / 2, tft.height() / 2 + 10);
    delay(1500);

    // WiFiMgr replaces WiFiManager
    WiFiMgr::begin();
    Serial.println("[Type D] WiFiMgr initialized.");

    // If not connected, display portal info
    if (!WiFiMgr::isConnected()) {
        displayPortalInfo();
    }

    UDPDetect::begin();

    // --- Start detection and web server modules ---
    Detect::begin();
    server8080.begin();
    FileMan::begin(server8080);
    Diag::begin(server8080);
    cmd_init(&server8080, &tft);
    UI::begin(&tft);

    Serial.printf("[Type D] Device ID: %d\n", Detect::getId());

    // --- Show a random image on WiFi success as well ---
    ImageDisplay::displayRandomImage();
}

void loop() {
    WiFiMgr::loop();

    // 1. Highest priority: About, brightness, menu overlays
    if (ui_about_isActive()) { ui_about_update(); return; }
    if (ui_bright_isVisible()) { ui_bright_update(); return; }
    if (UISet::isMenuVisible()) { UISet::update(); return; }
    UI::update();

    // 2. Run detection and UDP polling
    Detect::loop();
    UDPDetect::loop();

    // 3. Status overlay logic -- only show between images and if no UI/menu overlay is active
    bool anyUiActive = ui_about_isActive() || ui_bright_isVisible() || UISet::isMenuVisible() || UI::isMenuVisible();

    if (ImageDisplay::isDone() && UDPDetect::hasPacket() && !overlayPending && !showingXboxStatus && !anyUiActive) {
        lastXboxStatus = UDPDetect::getLatest(); // latch latest
        overlayPending = true;
        UDPDetect::acknowledge();
    }

    // Show overlay if pending (takes precedence over image display)
    if (overlayPending && !anyUiActive) {
        xbox_status::show(&tft, lastXboxStatus);
        lastStatusDisplay = millis();
        showingXboxStatus = true;
        overlayPending = false;
        return; // Show overlay, block image update
    }

    // If overlay is showing, time it out after 2s, then resume slideshow
    if (showingXboxStatus && !anyUiActive) {
        if (millis() - lastStatusDisplay > 2000) {
            showingXboxStatus = false;
            ImageDisplay::displayRandomImage();
        }
        return; // Block image update while overlay active
    }

    // 4. Only update image if overlay is not showing and not in a menu
    if (!UI::isMenuVisible()) {
        ImageDisplay::update();
    }

    cmd_serial_poll();
    
}

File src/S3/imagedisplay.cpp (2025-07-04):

#include <random>
#include <SPI.h>
#include "imagedisplay.h"
#include <vector>
#include <algorithm>
#include <AnimatedGIF.h>
#include <FFat.h>
#include <LovyanGFX.hpp>
#include "esp_heap_caps.h"
#include "disp_cfg.h"
#include <WiFi.h>
#include <esp_system.h>
#include <ctime>

class LGFX;

namespace ImageDisplay {

bool paused = false;
static std::default_random_engine rng;
static bool seeded = false;

static LGFX* _tft = nullptr;
static AnimatedGIF gif;
static Mode currentMode = MODE_RANDOM;
static std::vector<String> jpgList;
static std::vector<String> gifList;
static std::vector<String> randomStack;
static int imgIndex = 0;
static unsigned long lastImageChange = 0;
static bool currentIsGif = false;

// --- PATCH: Flag for deferred random image trigger ---
volatile bool g_triggerRandomImage = false;

// --- RAMGIFHandle for GIF-in-RAM logic ---
struct RAMGIFHandle {
    uint8_t *data;
    size_t size;
    size_t pos;
};
static RAMGIFHandle* s_gifHandle = nullptr;

static bool imageDone = false;

void removeFromPlaylist(const String& path) {
    auto removeIt = [&](std::vector<String>& list) {
        list.erase(std::remove(list.begin(), list.end(), path), list.end());
    };
    removeIt(jpgList);
    removeIt(gifList);
    removeIt(randomStack);
}

void setPaused(bool p) { paused = p; }

void drawNoImagesMessage(LGFX* tft) {
    tft->fillScreen(TFT_BLACK);

    String mainMsg = "Please upload your images";
    String ipMsg = "http://" + WiFi.localIP().toString() + ":8080";
    String footer = "Ya No0b!";

    uint16_t w, h;
    tft->setTextColor(TFT_WHITE, TFT_BLACK);

    tft->setTextSize(2);
    w = tft->textWidth(mainMsg);
    h = tft->fontHeight();
    tft->setCursor((tft->width() - w)/2, tft->height()/2 - 30);
    tft->print(mainMsg);

    tft->setTextSize(2);
    w = tft->textWidth(ipMsg);
    h = tft->fontHeight();
    tft->setCursor((tft->width() - w)/2, tft->height()/2);
    tft->print(ipMsg);

    tft->setTextSize(1);
    w = tft->textWidth(footer);
    h = tft->fontHeight();
    tft->setCursor((tft->width() - w)/2, tft->height() - h - 8);
    tft->print(footer);
}

// --- Utility: Always free GIF RAM handle/buffer safely ---
static void freeRamGifHandle() {
    if (s_gifHandle) {
        if (s_gifHandle->data) {
            heap_caps_free(s_gifHandle->data);
            s_gifHandle->data = nullptr;
        }
        delete s_gifHandle;
        s_gifHandle = nullptr;
    }
    currentIsGif = false;
}

// --- GIF RAM Callbacks (Larry Bank style) ---
void* GIFOpenRAM(const char*, int32_t* pSize) {
    if (!s_gifHandle) return nullptr;
    *pSize = s_gifHandle->size;
    return s_gifHandle;
}
void GIFCloseRAM(void* hptr) { /* No op. We free after playback (or on error). */ }
int32_t GIFReadRAM(GIFFILE* pFile, uint8_t* pBuf, int32_t iLen) {
    RAMGIFHandle* h = static_cast<RAMGIFHandle*>(pFile->fHandle);
    int32_t avail = h->size - h->pos;
    int32_t n = (iLen < avail) ? iLen : avail;
    if (n > 0) {
        memcpy(pBuf, h->data + h->pos, n);
        h->pos += n;
        pFile->iPos = h->pos;
    }
    return n;
}
int32_t GIFSeekRAM(GIFFILE* pFile, int32_t iPosition) {
    RAMGIFHandle* h = static_cast<RAMGIFHandle*>(pFile->fHandle);
    if (iPosition >= 0 && (size_t)iPosition < h->size) {
        h->pos = iPosition;
        pFile->iPos = iPosition;
        return iPosition;
    }
    return -1;
}

// --- GIF draw callback ---
void gifDraw(GIFDRAW* pDraw) {
    if (!_tft || !pDraw || !pDraw->pPalette || !pDraw->pPixels) return;
    int x_offset = (_tft->width() - pDraw->iWidth) / 2;
    int y_offset = (_tft->height() - pDraw->iHeight) / 2;
    int16_t y = pDraw->iY + pDraw->y;
    if (y < 0 || y >= _tft->height() || pDraw->iX >= _tft->width() || pDraw->iWidth < 1) return;
    static uint16_t lineBuffer[320];
    int copyWidth = std::min(pDraw->iWidth, 320); // Patch: avoid overflow
    for (int x = 0; x < copyWidth; x++) {
        lineBuffer[x] = pDraw->pPalette[pDraw->pPixels[x]];
    }
    _tft->pushImage(x_offset + pDraw->iX, y_offset + y, copyWidth, 1, lineBuffer);
}

void closeGif() {
    gif.close();
}

void begin(LGFX* tft) {
    _tft = tft;
    if (!seeded) {
        rng.seed(esp_random() ^ millis());
        seeded = true;
    }
    refreshFileLists();
    currentMode = MODE_RANDOM;
}

void setMode(Mode m) {
    currentMode = m;
    imgIndex = 0;
}

Mode getMode() {
    return currentMode;
}

void refreshFileLists() {
    jpgList.clear();
    gifList.clear();

    File jpgDir = FFat.open("/jpg");
    if (jpgDir && jpgDir.isDirectory()) {
        File f = jpgDir.openNextFile();
        while (f) {
            if (!f.isDirectory()) {
                String fn = String(f.name());
                fn.toLowerCase();
                if (fn.endsWith(".jpg") || fn.endsWith(".jpeg")) {
                    jpgList.push_back(String("/jpg/") + String(f.name()));
                }
            }
            f = jpgDir.openNextFile();
        }
    }

    File gifDir = FFat.open("/gif");
    if (gifDir && gifDir.isDirectory()) {
        File f = gifDir.openNextFile();
        while (f) {
            if (!f.isDirectory()) {
                String fn = String(f.name());
                fn.toLowerCase();
                if (fn.endsWith(".gif")) {
                    gifList.push_back(String("/gif/") + String(f.name()));
                }
            }
            f = gifDir.openNextFile();
        }
    }
}
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

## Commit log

2025-06-13 Type S Drill Guide
    [Type S Drill guide.stl]
2025-06-13 0.5.2
    GIF fix and conversion script
    [Type_D.ino, boot.cpp, detect.cpp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]
2025-06-14 STL's and images
    [Type S Bezel.stl, Type S Drill guide.stl, Washer.stl]
2025-06-14 STL correction
    [Type S Drill guide.stl]
2025-06-20 LED Tweaks
2025-06-21 0.7.1 Beta
    Detection fixes, wifimgr fixes, image display patch, and Duke install images and STL's
    [Duke Guide.stl, Duke Spacer.stl]
2025-07-04 ESP32-S3 Screen Support
2025-07-04 Update README.md
    Started to add ESP32-S3 info
2025-07-16 ESP32 S3 Variant
2025-07-22 Support for clone boards
2025-08-08 EXP PCB
    Added a little PCB for the expansion module
    [BOM.xlsx]
2025-08-22 HDD Key fixes
    Added fixes for RC4 decoding of the HDD KEY
    [Type_D_exp.ino]
2025-09-04 EXP firmware overhaul
    This release focuses on **safe, low‑jitter, read‑only SMBus access** across *all* Original Xbox revisions, with special attention to **v1.6 (Xcalibur)**. It also hardens UDP behavior, removes potential EEPROM write vectors, and reduces serial/log overhead.
    ---
    ## Highlights
    - **STOP‑only SMBus transactions** (no repeated‑starts) by default for v1.6 safety.
    - **Cross‑core SMBus mutex** so only one reader touches the bus at a time.
    - **Round‑robin polling** (CPU, Board, Fan, Idle) to avoid bursts.
    - **Bounded backoff + jitter** to prevent phase‑locking and lower bus pressure.
    - **Safe Xcalibur mode probe** (single register, periodic) to track runtime mode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
    [Type_D_exp.ino]
2025-10-25 1.4 Resolution fix
    Corrected resolution handling for focus encoders
    [Type_D_exp.ino]
